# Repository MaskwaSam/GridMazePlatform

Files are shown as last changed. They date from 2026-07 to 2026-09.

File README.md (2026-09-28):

# Grid Maze Platform

Parametric Rhino 8 generator for a first-pass modular grid maze platform.

The shared platform system uses:

- 200 mm x 200 mm tile footprint.
- 10 mm total tile height.
- Selectable underside connector pockets for `north`, `south`, `east`, and `west`.
- 8 mm pocket depth from the underside, leaving a 2 mm top skin.
- A removable underside bridge connector that lays flat in a matching recess.
- Flat double-dovetail connector footprint:
  50 mm dovetail length into each board, 22 mm neck width, 46 mm inner tail width,
  6 mm connector thickness, and 0.2 mm printable clearance per side.
- No quarter-turn prongs, ramps, undercuts, or overhanging lock features.

The baseline platform generator intentionally leaves walls out. The working Rhino
model contains the user-authored straight maze-piece geometry with its platform and
tall walls; the wall-variant generators use that modeled geometry as their source
instead of rebuilding its profile from guessed dimensions.

## Files

- `params/maze_platform_v1.json` contains the default dimensions.
- `enabled_sides` controls which dovetail pockets are generated. Default: all four sides.
- `scripts/generate_grid_maze_platform.py` validates parameters and generates Rhino geometry.
- `scripts/generate_maze_piece_variants.py` derives the five-piece 200 mm starter set from the working Rhino geometry.
- `scripts/generate_h2d_compatible_platforms.py` creates 200 x 300 mm and 300 x 300 mm H2D adapter platforms with the exact reviewed X1C pocket geometry.
- `scripts/generate_h2d_maze_variants.py` adds the Rhino-authored walls to five maze layouts at each H2D platform size and two 45-degree special pieces.
- `scripts/generate_30deg_ramp.py` creates the X1C-compatible straight-corridor ramp that rises 2 mm above the wall top.
- `scripts/generate_30deg_up_down_ramp.py` creates the symmetric 200 x 300 challenge ramp with a centred ridge.
- `scripts/generate_challenge_ramp_variants.py` creates the twelve-piece 200 x 300 H2D challenge collection.
- `scripts/optimize_for_3d_printing.py` ranks printable dovetail/clearance variants without requiring Rhino.
- `scripts/render_piece_catalog.py` renders the generated STL files for the offline visual catalog.
- `tests/test_platform_spec.py` performs fast CPython checks that do not require Rhino.
- `reference/photos/` contains photos of printed prototypes; these are visual references, not dimensional source files.
- [`docs/index.html`](docs/index.html) is the human-readable catalog with geometry renders and connection diagrams.
- [`game/`](game/) is the self-hosted Chromebook game for programming a Three.js sphere robot with Blocks or Python.
- `output/` is where generated `.3dm` and `.stl` files are written.

The Rhino model at `output/grid_maze_platform_10mm_v1.3dm` is the authoritative
geometry for new maze-piece variants. Prototype photos should be used to understand
the intended assembly and appearance, while dimensions should be taken from the
Rhino geometry and parameter files.

## Project Handoff — 2026-08-29

The current visual catalog contains 33 generated pieces across six families:

- 5 original 200 x 200 mm X1C wall pieces;
- 2 blank H2D adapter platforms;
- 12 H2D wall and 45-degree adapter pieces;
- 1 X1C 30-degree rising ramp;
- 1 H2D 200 x 300 mm up-and-down ramp; and
- 12 H2D 200 x 300 mm challenge-ramp variations.

Open [`docs/index.html`](docs/index.html) directly in a browser to review the
renders and download the printable files. Its controls combine free-text search
with mutually exclusive platform and piece-type filters. Select **H2D only** to
hide the original X1C/200-only pieces. Press Escape to clear the search field;
use **Reset filters** to restore the complete catalog. All content remains visible
if JavaScript is unavailable.

Every new H2D platform keeps the reviewed X1C connector geometry unchanged and
uses one connector pocket centred on each side. The generated files in `output/`
remain the printable/editable deliverables; the catalog images are previews only.

Closeout verification: `python3 -B -m unittest discover -s tests -p 'test_*.py'`
passes all 88 tests, including generated-solid checks, the standalone game
contract, and catalog metadata, local-link, accessibility-state, and no-JavaScript
fallback checks. The catalog's inline JavaScript also passed syntax and filter-logic
validation; Maskwa Maze Lab additionally passed live Chromium interaction testing at
the 1366 x 768 Chromebook viewport.

Before a production print, slice the 300 x 300 mm platform with the intended H2D
nozzle/profile and confirm the usable-bed boundary, excluded zones, skirt, and brim.
Print a small connector test first when changing filament, nozzle, or clearance;
the CAD compatibility does not replace a physical fit check.

## Maskwa Maze Lab — Standalone Chromebook Game

[`game/index.html`](game/index.html) is the playable vertical slice. It uses the
generated straight, corner, and end-piece STLs to provide seven progressively
longer courses: Straight Start, Starter L-Turn, Mirror Left, Double Turn, U-Turn
Trail, Return Route, and Four-Turn Finish. Students choose a maze, drag the sphere robot from its tray
anywhere onto the highlighted starting piece, finish an intentionally incomplete program in
Blockly or Python, and press Run. The deterministic 60 Hz simulation reports
collisions and succeeds only when the robot enters the goal. Run and Reset preserve
the student's exact collision-safe drop position rather than snapping to the tile center.
The rendered sphere and physics collider are both 70 mm in diameter (35 mm
radius), exactly 35% of one 200 mm X1C plate width.

Every Run keeps the exact executed code, result, ending pose, and wall-impact
count in a per-maze history; students can also create explicit Save checkpoints
and compare changed lines. The latest 20 entries per maze remain in browser-local
storage. Export writes all maze work and history to one portable Maskwa Maze Lab JSON file.
Import validates the complete file, preserves replaced local code in history, and
never runs imported student code automatically. It also restores the exported
active maze. Failed autosaves remain visibly flagged, block a lossy maze switch,
and Export can produce an in-memory recovery copy when browser storage is
unavailable. If the complete project exceeds the portable-file limit, Export
falls back to a clearly named current-maze-only recovery file.

The app is self-hosted: Three.js, Blockly, the Python generator, and the minimal
Pyodide runtime are stored under `game/vendor/`, with their license notices. It
does not require a CDN. Serve it over HTTP rather than opening it with `file://`:

```bash
python3 -m http.server 8766 --directory game
```

Then open `http://127.0.0.1:8766/` in Chrome or ChromeOS. Validate the standalone
bundle and its deterministic reference solution with:

```bash
node game/tests/validate.mjs
```

The MVP has seven flat continuous-corridor levels with a picker, per-level program
saves, and a Next maze action. Ramp physics, branching T/cross-piece levels, the
rendered 8 x 8 shell matrix, and physical BOLT+ connectivity remain later additions. See
[`game/README.md`](game/README.md) for the student workflow, architecture, safety
boundary, offline behavior, and current limitations.

### Production acceptance — 2026-08-30

Maskwa Maze Lab is live at <https://mazelab.spatterson.ca>. The accepted release
is commit `3b51f351a5083f8f7886f102165514c8ed166bf9`, immutable image
`mazelab:3b51f351a508-3adc281d9e56`, and runtime digest
`3adc281d9e564466a6f78de723d326c1807c5490816514c1626e8390e960a3f2`.
Public HTTP, the version 40 offline cache, all seven Beginning levels, Blocks,
local Python, the 390 x 844 mobile layout, and the no-external-request boundary
passed acceptance. The operator completed visual acceptance and reported being
very happy with the result.

The Cloudflare connector and running neighboring services were preserved during
the update. The prior image `mazelab:a484fc7c9452-463b9b81691d` remains retained
for rollback. Maze Lab remains a static, local-first application: student work
stays in each browser, and the dormant multiplayer modules do not expose a
WebSocket or `/ws` service. This production acceptance applies only to the
committed game and deployment surface; the separate CAD/catalogue work remains
outside the deployed artifact.

## Maze Piece Starter Set

The canonical set keeps the existing 200 mm square module and includes straight,
corner, T-junction, cross-junction, and end/dead-end pieces. Other orientations are
made by rotating these five pieces.

Generate the Rhino and STL files with Rhino 8's `rhinocode` command:

```bash
/Applications/Rhino\ 8.app/Contents/Resources/bin/rhinocode script \
  "$(pwd)/scripts/generate_maze_piece_variants.py"
```

Then validate the exported artifacts and refresh the catalog images:

```bash
python3 -B scripts/generate_maze_piece_variants.py --check --require-outputs
python3 -B scripts/render_piece_catalog.py
```

Generated variants are written to `output/variants/`.

The variant generator pins the reviewed source model's SHA-256 fingerprint so it
cannot silently select different geometry after the Rhino file changes. After an
intentional source edit, review the new geometry before updating
`EXPECTED_SOURCE_SHA256` in the generator.

## H2D-Compatible Adapter Platforms

The H2D set expands the printable area while retaining the current X1C maze
connector at its original size and clearance:

- `200 x 300 mm`: one connector bay centred on each of its four edges.
- `300 x 300 mm`: one connector bay centred on each of its four edges.
- Both platforms remain 10 mm high, with 8 mm-deep underside pockets and a
  2 mm top skin.

On a 300 mm edge, an ordinary 200 x 200 mm X1C platform attaches in the centre,
leaving a 50 mm shoulder at each end of the larger edge. The connector itself is
not scaled or altered.

Generate the H2D adapters through Rhino 8, then validate their saved geometry:

```bash
/Applications/Rhino\ 8.app/Contents/Resources/bin/rhinocode script \
  "$(pwd)/scripts/generate_h2d_compatible_platforms.py"
python3 -B scripts/generate_h2d_compatible_platforms.py --check --require-outputs
python3 -B scripts/render_piece_catalog.py --collection h2d
```

Generated files are written to `output/h2d-platforms/`. For H2D dual-nozzle
printing, orient the 200 x 300 mm adapter with its 300 mm dimension along the
320 mm bed axis. The 300 x 300 mm adapter uses the dual-nozzle width exactly, so
the single-nozzle build envelope is the more forgiving choice. Confirm the
sliced footprint, skirt or brim, and excluded zones before printing either part.

## H2D Wall Variants

The larger wall set contains straight, corner, T-junction, cross-junction, and
end/dead-end pieces at both 200 x 300 mm and 300 x 300 mm. Every piece retains one
centred X1C connector pocket per side. A wall-bearing transition connects a centred
200 mm X1C edge to a centred 300 mm H2D edge. A four-way 300 x 300 mm hub provides
centred 200 mm X1C openings and connectors on all four sides.

The walls come from the separate closed wall solids in the working Rhino file.
For a 300 mm edge, the generator preserves both designed wall ends and inserts
100 mm through a verified uniform middle section. It does not scale the wall
thickness, height, or end transitions.

The transition occupies a 300 x 200 mm envelope. Its side walls run straight for
75 mm, widen by 50 mm over a 50 mm run at exactly 45 degrees, and then run straight
for another 75 mm. It has one centred connector pocket on each open end and no
connector pockets on its angled sides. A continuous sharp-miter sweep carries the
verified Rhino wall profile through both bends without overlap ribs.

The four-way hub uses four exact 45-degree walls. Each wall is the source-derived
1.2 mm vertical panel from Z10 to Z82; the authored 19.2 mm sloped reinforcement
foot is intentionally omitted from this piece. This removes the triangular foot
corners while retaining the wall height, four centred openings, and connector scale.

Generate, validate, and render the twelve-piece set with:

```bash
/Applications/Rhino\ 8.app/Contents/Resources/bin/rhinocode script \
  "$(pwd)/scripts/generate_h2d_maze_variants.py"
python3 -B scripts/generate_h2d_maze_variants.py --check --require-outputs
python3 -B scripts/render_piece_catalog.py --collection h2d-walls
```

The STL files and combined editable Rhino model are written to
`output/h2d-wall-variants/`.

## 30 Degree Ramp

The ramp is a 200 x 200 mm X1C-compatible straight-corridor tile with one centred
connector pocket on every side and the two authored side walls. Its floor remains
flat at Z10 for a 71.828 mm south approach, then rises at exactly 30 degrees to
Z84 at the north edge. That is 2 mm above the Z82 wall top. The 74 mm rise fixes
the horizontal run at 128.172 mm and the sloped surface length at exactly 148 mm.

The closed ramp wedge is 161.6 mm wide, centred between X19.2 and X180.8 so it
stays within the exact floor-level corridor between the authored wall feet. Rotate
the finished tile to place the high edge in another direction. The high-side pocket
remains mechanically compatible, but its Z84 ramp surface is intentionally not a
level continuation of a normal Z10 tile.

Generate, validate, and render the ramp with:

```bash
/Applications/Rhino\ 8.app/Contents/Resources/bin/rhinocode script \
  "$(pwd)/scripts/generate_30deg_ramp.py"
python3 -B scripts/generate_30deg_ramp.py --check --require-outputs
python3 -B scripts/render_piece_catalog.py --collection ramp
```

The printable STL and editable one-piece Rhino model are written to `output/ramp/`.

### 200 x 300 Up-and-Down Challenge Ramp

The challenge piece keeps both entries at the normal Z10 floor level. After a
21.828 mm flat approach, it climbs at exactly 30 degrees to a centred Z84 ridge,
then descends symmetrically at 30 degrees to a matching 21.828 mm exit approach.
Each side of the ridge has a 74 mm rise, 128.172 mm horizontal run, and 148 mm
sloped length. The peak is 2 mm above the Z82 wall top.

Its 200 x 300 mm H2D platform retains one centred X1C pocket on every side and
uses the reviewed 300 mm extensions of the two authored straight walls. The ramp
remains 161.6 mm wide between the wall feet. Generate and verify it with:

```bash
/Applications/Rhino\ 8.app/Contents/Resources/bin/rhinocode script \
  "$(pwd)/scripts/generate_30deg_up_down_ramp.py"
python3 -B scripts/generate_30deg_up_down_ramp.py --check --require-outputs
python3 -B scripts/render_piece_catalog.py --collection challenge-ramp
```

Its STL and editable Rhino model are written to `output/challenge-ramp/`.

### 200 x 300 Challenge Ramp Collection

The extended challenge collection reuses the same H2D platform, exact centred
X1C connector pocket on every side, 161.6 mm ramp width, and source-derived wall
geometry. It contains twelve printable profiles:

- a Z84 hill with a 30 mm flat top;
- two 30 mm-rise humps;
- the Z84 ridge with twelve shallow traction ribs;
- centred 20, 40, and 60 mm-rise hills;
- an asymmetric ridge offset to Y100;
- a Z84 crest rounded to a 15 mm radius;
- a Z60 stopping platform that is 80 mm long;
- one-wall and wall-free versions of the Z84 ridge; and
- a directional challenge with a smooth 30-degree climb and ten steps down.

Generate, validate, and render the collection with:

```bash
/Applications/Rhino\ 8.app/Contents/Resources/bin/rhinocode script \
  "$(pwd)/scripts/generate_challenge_ramp_variants.py"
python3 -B scripts/generate_challenge_ramp_variants.py --check --require-outputs
python3 -B scripts/render_piece_catalog.py --collection challenge-ramp-variants
```

The twelve STLs and their combined editable Rhino model are written to
`output/challenge-ramp-variants/`.

## Generate

From Rhino 8, with model units in millimeters:

```text
-_RunPythonScript "<repo-path>/scripts/generate_grid_maze_platform.py"
```

Replace `<repo-path>` with the folder where you cloned this repository.

The script also supports Rhino headless execution and writes status files to:

```text
output/grid_maze_platform_status.txt
<Rhino system temp>/grid_maze_platform_status.txt
```

Expected output files:

- `output/grid_maze_platform_10mm_v1.3dm`
- `output/grid_maze_platform_tile_v1.stl`
- `output/grid_maze_platform_bridge_v1.stl`
- `output/grid_maze_platform_recess_cutter_v1.stl` contains the full board-layout dovetail cutter for all four underside connector beds.

Rhino may include a local macOS render-cache username in otherwise portable
`.3dm` metadata. The checked-in model is sanitized with the length-preserving
`scripts/sanitize_3dm_metadata.py` helper; generated geometry is unchanged.

## Fast Checks

These checks only validate the parameter math and can run outside Rhino:

```bash
python3 -B -m unittest discover -s tests
python3 -B scripts/generate_grid_maze_platform.py --check
python3 -B scripts/generate_grid_maze_platform.py --check --sides north,east
python3 -B scripts/optimize_for_3d_printing.py
```

To generate only selected sides from Rhino, edit `enabled_sides` in
`params/maze_platform_v1.json` before running the Rhino script. From CPython checks
and non-Rhino runs, `--sides north,east` can be used as a quick override.

## 3D Print Optimization

The optimizer reads the current platform parameters and scores small dovetail
variants for FDM printing. It does not change the main parameter file unless you
ask it to write a separate optimized JSON.

```bash
python3 -B scripts/optimize_for_3d_printing.py --profile tight
python3 -B scripts/optimize_for_3d_printing.py --profile balanced --write-report
python3 -B scripts/optimize_for_3d_printing.py --profile balanced --write-params
```

Profiles:

- `tight` keeps the requested 0.20 mm clearance as the target.
- `balanced` targets 0.25 mm clearance for a more forgiving first FDM prototype.
- `durable` favors a slightly thicker connector and lower vertical slack.

Generated optional files:

- `output/print_optimization_report.md`
- `params/maze_platform_print_optimized.json`

## Current Assumptions

- This is tabletop-maze hardware, not a child/adult load-bearing floor system.
- The underside bridge is a flat printed dovetail part that sits inside the 8 mm underside recess.
- The platform-side pocket is a simple subtractive dovetail bed for the connector footprint.
- The exported recess cutter includes the board layout, not just the loose connector footprint.
- The current flat connector is shape-fit only; screw/nut retention can be added next.

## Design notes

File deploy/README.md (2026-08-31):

# Maskwa Maze Lab production deployment

This package serves the committed standalone game at
`https://mazelab.spatterson.ca` from a dedicated, non-root NGINX container.
The application has no backend, server-side student data, host port, remote
runtime dependency, or persistent volume. Student code, placements, and attempt
history stay in the browser; `.maskwamaze` export/import is the portable recovery
path.

The game includes dormant versioned multiplayer client modules, but this release
still has no WebSocket service and no `/ws` route. Loading the app does not open a
socket. Do not point the client at an ad hoc WebSocket server. The authority,
privacy, ordering, security, two-Chromebook, and rollback gates for a future
same-origin `wss://mazelab.spatterson.ca/ws` service are specified in
`game/MULTIPLAYER.md`.

## Request path and service URL

```text
Browser -> Cloudflare edge -> managed spatterson-site Tunnel
        -> standalone spatterson-cloudflared -> mazelab_edge
        -> mazelab:8080 -> NGINX
```

Use these Cloudflare **Published application** fields only after private origin
verification succeeds:

- Subdomain: `mazelab`
- Domain: `spatterson.ca`
- Path: leave blank
- Service URL: `http://mazelab:8080`

The Compose project joins only the pre-created internal `mazelab_edge` network.
Attach the existing connector to that network without disconnecting it from any
existing network and without restarting or recreating the connector. Do not
publish a host port, change router forwarding, modify the main-site `web`
service, or touch PatterDraw, GeoGon, Moodle, or `mesconline.ca`.

## Release gate

1. Commit the exact `game/`, `deploy/`, level-generator, and two release-test
   files.
2. Run `deploy/prepare-release.sh /absolute/new/release-directory`. The script
   refuses an uncommitted release surface, derives the full commit and runtime
   digest, archives that exact commit, reruns the game/deployment tests from the
   extracted archive, and writes `release.env` plus a human-readable receipt.
   Unrelated CAD/catalog work may remain in the checkout because it is not copied
   into or used to label this release.
3. Independently verify the source-archive SHA-256 from the receipt after every
   transfer and before extraction. Load only the generated `release.env`; do not
   hand-type release identity values.
4. Render the Compose model and confirm that it contains no `ports` entry and
   names only `mazelab_edge`.

The image build checks the 40-character Git commit and both 64-character receipt
digests, recomputes the exact allowlisted runtime digest, rejects symlinks, copies
only the declared runtime surface, validates NGINX, and records the release
identity in OCI labels. The source-archive digest is independently rechecked
before remote extraction; the container never trusts a dirty working directory.

## Initial deployment gates

Before any mutation, record:

- the current public DNS/Tunnel route state for `mazelab.spatterson.ca`;
- the absence or exact state of a `mazelab` container, image, target directory,
  and `mazelab_edge` network;
- the connector container ID, image, restart count, and complete network list;
- neighboring service health and host listeners.

Create only an internal `mazelab_edge` network. Build and start only the
`mazelab` service while the connector is still absent from that network. Run
`deploy/verify-running.sh private` and prove the correct Host returns the health
endpoint and app, an unknown Host is rejected, the WebAssembly response uses
`application/wasm`, the service worker and HTML are `no-store`, missing files
are 404, and the container is non-root, read-only, capability-free,
resource-bounded, log-bounded, and has no published host port.

For a private origin temporarily exposed to the operator workstation, run
`python3 deploy/verify-browser.py --base-url <private-origin>`. It proves that
Three.js, Blockly, and the local Pyodide worker initialize under the production
headers and that the page makes no cross-origin application requests. Remove
the temporary operator-only port or proxy immediately after this check; the
production Compose model must remain host-port-free.

After private acceptance, attach the existing connector to `mazelab_edge`
without restarting it. Run `deploy/verify-running.sh connector-attached`, then
add the Cloudflare route above. The attached verifier requires the pre-attachment
connector ID, image ID, restart count, and sorted network list in the documented
`MAZELAB_CONNECTOR_*_BEFORE` variables; it rejects identity, restart, or neighboring
network drift and probes `mazelab:8080` from a disposable process sharing the
connector's network namespace. Public acceptance must cover HTTPS, the expected
headers, a fresh-profile PWA load, all seven mazes, Blockly and Python execution,
the local Pyodide worker, a `.maskwamaze` export/import round trip, offline reload,
fullscreen, and absence of external application requests. Recheck
`spatterson.ca`, `bible.spatterson.ca`, `draw.spatterson.ca`,
`geogon.spatterson.ca`, and `mesconline.ca` after attachment and after route
activation.

## Rollback

Retain the exact pre-deploy connector and public route state, release archive,
image ID, labels, rendered Compose model, and verification output through the
rollback window. Initial rollback is narrowly scoped:

1. Remove only the `mazelab.spatterson.ca` Published application route and
   verify or remove only its managed DNS record.
2. Disconnect only `spatterson-cloudflared` from `mazelab_edge`; do not restart
   or recreate the connector.
3. Stop only the `mazelab` Compose project.
4. Remove `mazelab_edge` only after proving that no container remains attached.

Do not delete the staged release or accepted image until the rollback window has
closed.

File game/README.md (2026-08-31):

# Maskwa Maze Lab — standalone Chromebook MVP

Maskwa Maze Lab is a static, self-hosted Three.js game with seven progressively
longer printable-piece mazes. A student chooses a level, places the sphere robot
anywhere collision-safe on the highlighted starting piece, writes a program with
Blockly or Python, presses Run,
and watches the robot attempt the same deterministic maze every time. The
robot accelerates, rolls with momentum, actively brakes, and rebounds from maze
walls while continuing the student's command. Its white band and orange tracker
rotate with the physical shell so students can see its speed and rolling direction;
the upright arrow remains the separate facing indicator.

The game uses the printable models' millimetre scale. The sphere is 70 mm in
diameter (35 mm radius), exactly 35% of a 200 mm X1C plate width. Its rendered
mesh and physics collider use the same radius.

## Run it

From the repository root:

```bash
python3 -m http.server 8766 --directory game
```

Then open `http://127.0.0.1:8766/` in current Chrome or ChromeOS. Do not open
`index.html` with `file://`; browser modules, workers, WebAssembly, and offline
caching require HTTP(S). A production static host must serve `.wasm` as
`application/wasm`.

On a phone, portrait mode presents the maze and Coding Workspace as a compact
top-to-bottom workflow with a sticky level header and 44 px primary touch
targets. Narrow screens stack the maze title above its controls so labels stay
readable. Short landscape screens use a balanced side-by-side view and remove
nonessential maze overlays so placing the robot remains practical. Safe-area
insets are respected around notches and home indicators; rotate the device at
any time and the Three.js and Blockly surfaces resize without discarding student
work.

The first Python run loads about 11.7 MiB of local Pyodide files. After the
service worker finishes caching, the game can reload offline from the same
origin. There are no CDN or external runtime requests.

## Student workflow

1. Choose any of the seven unlocked mazes. The sequence progresses from a
   Straight Start, Starter L-Turn, Mirror Left, Double Turn, U-Turn Trail,
   Return Route, and Four-Turn Finish challenges.
2. Drag the robot from its tray anywhere onto the highlighted blue START piece.
   The exact release point becomes that attempt's starting position. **Place at
   start center** remains an explicit shortcut. Every classroom level starts
   facing north at world bearing `0°`. The `N` on the START AREA label means
   North and marks the robot’s initial forward direction. After the robot turns,
   its new facing becomes the reference for subsequent forward commands.
3. Complete the deliberately unfinished starter blocks, or switch to Python.
4. Press **Run**. **Stop** terminates the Python worker. **Reset** restores the
   exact position the student chose and clears the trail.
   When the maze and robot have been idle for 20 seconds, the camera begins a
   slow orbit for a clearer view. Any pointer, wheel, or keyboard interaction
   stops the orbit; reduced-motion preferences disable it.
   Click the maze to focus it, then press **Ctrl+R** to start that orbit
   immediately. The browser's normal reload shortcut remains available whenever
   focus is outside the maze view.
   Use the expand button in either panel header to focus the maze or Coding Workspace
   fullscreen. Press the same button or `Esc` to return to the two-panel view.
5. Bring the sphere to a complete stop on the green GOAL disc. Crossing the
   disc while still moving does not solve the maze. Wall impacts are counted in
   telemetry, but they bounce the robot back into the maze and do not terminate
   the program.
6. Select **Next maze** after a successful run, or use the maze picker at any
   time. Blocks and independent Python are saved separately for each level.
7. Use **Attempts** to compare the exact code, result, wall impacts, and changed
   line count from oldest to newest. Every Run is recorded automatically; **Save**
   adds a deliberate code-version checkpoint. The latest 20 entries are kept for
   each maze.

Use **Export** to download one `Maskwa-Maze-Lab-Work-YYYY-MM-DD.maskwamaze.json` file
containing every saved maze, its exact editor state, robot placement, and attempt
history. **Import** accepts that file on another Chromebook and continues to
accept earlier `.mazebot.json` project files. It validates the
entire project before changing local storage, replaces only the mazes included in
the file, and keeps the current local code for each replaced maze as a **Before
import** history entry. Imported code is displayed but never run automatically.
Mazes omitted from the file keep their local work, and the maze that was active
when the project was exported opens after import.

Python editing is limited to the same 20,000 characters accepted by the local
runtime. If an autosave fails because browser storage is blocked or full, the UI
keeps a visible warning, prevents a maze change that would hide the unsaved work,
and **Export** still attempts to download an in-memory recovery copy containing
the current maze. If the complete project has grown beyond the 3 MB portable-file
limit, Export downloads a clearly named current-maze-only recovery file instead.

Blocks generate Python one way. As soon as a student edits the Python buffer it
becomes independent; edits never alter or discard the saved blocks. The UI
labels this state and asks before replacing edited Python with freshly generated
block code. Blockly state, Python state, active editor, current level, and the
exact chosen starting position are saved to browser local storage. The v3 save
format keeps one program record plus a bounded attempt history per maze, and
imports the prior robot-relative v2 record without deleting it. The portable
project file identifies its schema and robot-relative heading rules so an
incompatible file is rejected before any work changes. Older absolute-heading v1
data remains as an untouched backup and is not silently executed under the newer
relative-heading rules.

Python accepts both `await set_main_led("#008cff")` and the RGB-number
`await set_main_led(0, 140, 255)` form.

Motion angles are robot-relative. `roll(0, ...)` always means forward from the
sphere's current facing; `roll(90, ...)` turns right before rolling, and
`roll(-90, ...)` turns left. `spin(90, ...)` turns right in place and makes that
new facing the reference for the next command, so a following `roll(0, ...)`
continues in the direction established by the spin. Telemetry reports the
resulting world bearing from the original north-facing start.

## Device settings

The header **Settings** menu stores presentation and convenience choices only on
the current browser device. It includes idle camera tour, reduced motion, a
fog-free clearer view, travel trail, impact markers, ground grid, and optional
reset confirmation. It also has an opt-in **Xbox controller** switch. Pair the
controller in ChromeOS Bluetooth first, return to the game, enable the switch,
and press any controller button. The status card identifies whether the browser
is waiting, connected, disconnected, or unsupported and shows the complete
button map. Controller support starts off and performs no polling while disabled.

The Xbox mapping is A for Place/Run, B for Stop, X for Reset, Y for
Blocks/Python, View for Attempts, Menu for Settings, and the bumpers or left/right
D-pad buttons for maze navigation. These buttons operate the game workflow only;
they never steer the sphere. Robot motion and turning still come exclusively
from the student's Blocks or Python program, with the same timing and physics.

Defaults keep the tour, trail, impact markers, and grid on;
the other options start off. Reduced motion changes camera and sphere
animation only, never timing, collision, bounce, heading, or goal physics.

Settings use their own versioned local-storage record. They are not included in
student autosaves, attempt history, Export files, or Import, so moving class work
between Chromebooks cannot silently change a device's accessibility preferences.
**Restore defaults** changes only these settings and leaves every program and
attempt untouched.

## Architecture and safety boundary

- `levels/*.json` describes each X1C route using the three existing STL models,
  including physical end-caps behind START and GOAL. Every file records visual
  transforms, start/goal poses, physics constants, a logical wall polygon, and a
  deterministic reference program.
- `js/levels.js` is the ordered classroom catalogue used by the picker and the
  Next maze action. `scripts/generate_game_levels.mjs` converts short 200 mm grid
  paths into correctly rotated printable pieces, collision outlines, and reference
  programs. Run it with `--write` after adding a path, or without an option to
  check that generated JSON is current.
- `js/simulation.js` displays the source STL meshes. Collision uses both the
  level boundary and wall segments generated from every printable tile's closed
  sides. A final containment check refuses to render any illegal position. This
  stays responsive on Chromebooks without relying on expensive triangle meshes.
- `js/level-logic.js` is the deterministic 60 Hz rolling-physics contract shared
  by the browser and validation script. Speed 160 targets 100 mm/s, acceleration
  and braking change velocity over time, and wall normals produce damped rebounds.
- `js/blocks.js` defines 13 custom blocks for sphere-robot commands: motion,
  LEDs, matrix pixels, and sensor reads, with Python generators.
- `js/python-worker.js` runs student Python inside a dedicated worker. It rejects
  imports, attribute access, classes, globals, and reserved names; only safe
  built-ins and the allowlisted robot RPC functions enter the student namespace.
- `js/python-runtime.js` enforces a 20,000-character program limit, a 25-second
  run limit, and hard termination for Stop. Termination/recreation avoids a
  SharedArrayBuffer or cross-origin-isolation requirement on Chromebooks.
- `js/storage.js` owns per-level autosave, the latest-20 code history, and the
  versioned portable JSON contract. Imports are size-limited, schema-checked,
  Blockly-validated, staged in memory, and committed with one local-storage
  write only after student confirmation.
- `js/game-actions.js` is the shared workflow boundary for on-screen and Xbox
  controller input. `js/gamepad.js` adapts the browser Gamepad API into rising-edge
  semantic actions without held-button repeats or direct robot steering.
- The multiplayer protocol, immutable session, transport, and client modules are
  dormant groundwork for a later authoritative WebSocket service. The current
  release remains offline by default and opens no socket. See
  [MULTIPLAYER.md](MULTIPLAYER.md) for the privacy, ordering, authority, and
  deployment contract.

This is an instructional sandbox, not a security boundary for hostile code.
The AST restrictions, isolated worker, program limit, and hard timeout reduce
accidental misuse; a school deployment should still use an origin containing no
sensitive data or authenticated application APIs.

## Validate

From the repository root:

```bash
node game/tests/validate.mjs
```

The validation checks local-only dependencies, JavaScript syntax, required UI
controls, the exact 13 custom blocks, worker restrictions, STL integrity, wall
bounce behavior, command semantics, catalogue/cache completeness, per-level save
isolation, attempt lifecycle, loss-resistant import/export behavior, and every
level's deterministic reference solution. A maze level is
not accepted unless its start and goal are legal, every printable opening connects
correctly, its polygon matches the printed corridor, and its saved student-command
route reaches the goal without an impact.
The three canonical X1C meshes are checksum-pinned, and the validator reads the
top-wall orientation directly from each STL. A rotated or changed printable wall
therefore cannot silently drift away from the logical collision profile.

## Current MVP limits

- The seven included routes are continuous corridors made from end, straight,
  and corner pieces. True branching mazes require adding the printable T and
  four-way pieces to the game geometry and collision profiles.
- There is no visual level builder yet; new continuous routes are currently
  defined as grid paths in the generator script.
- Physics is currently a deterministic 2-D rolling model. Ramps, falling, and
  vertical gravity are not simulated yet.
- Matrix commands preserve an 8×8 virtual state but do not yet render a matrix
  on the sphere shell.
- Python deliberately excludes imports and attribute access, so lessons use the
  provided robot functions and safe core language constructs.
- No physical-robot connection, accounts, live multiplayer server, or
  leaderboard. Multiplayer-ready client boundaries are present but remain
  offline until a separately reviewed server is explicitly configured.

See `THIRD_PARTY_NOTICES.md` for local runtime licenses.

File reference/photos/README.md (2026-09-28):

# Prototype Photos

- `IMG_6221-preview.jpg` shows the existing red platform panels and white
  maze-wall pieces assembled as straight runs and a junction. The shared JPEG
  has no EXIF metadata.
- The untouched camera original, `IMG_6221.HEIC`, is retained locally and is
  excluded from the public repository.

These photos document the intended physical system. They are not scale references.
Use `output/grid_maze_platform_10mm_v1.3dm` and the files in `params/` for dimensions
when creating additional pieces.

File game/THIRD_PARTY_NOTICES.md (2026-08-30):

# Third-party notices

Maskwa Maze Lab is self-hosted and makes no CDN requests. The following local
runtime files are redistributed unchanged:

- Three.js 0.181.2 core/module builds and its STLLoader/OrbitControls examples — MIT License.
  See `vendor/licenses/Three-MIT.txt`.
- Blockly 13.1.1 and its Python generator — Apache License 2.0.
  See `vendor/licenses/Blockly-Apache-2.0.txt`.
- Pyodide 0.29.0 core runtime — Mozilla Public License 2.0.
  See `vendor/licenses/Pyodide-MPL-2.0.txt`.

The three STL files in `assets/stl/` are copies of the project's own tested
X1C maze-piece outputs. They remain governed by the project-level license.

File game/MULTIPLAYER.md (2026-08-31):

# Maskwa Maze Lab multiplayer contract

## Current release status

Maskwa Maze Lab is still an offline-first, single-student game. The production
container is static NGINX and does **not** expose `/ws`, create rooms, or send
student data to a server. The multiplayer modules in this release are a dormant,
tested client boundary for a later server implementation; they do not activate a
network connection by themselves.

This distinction is intentional. A classroom release must not quietly begin
transmitting student activity just because multiplayer-ready code is present.

## Client boundaries

- `js/game-actions.js` normalizes touch, mouse, keyboard, and controller workflow
  actions before the game handles them. Only placement, Run, Stop, Reset,
  Run-again, and maze-navigation actions are shareable. Settings, attempt-history
  views, and editor-mode changes remain device-local.
- `js/multiplayer-protocol.js` owns the version-1 wire envelope, strict message
  and payload validation, message-size limit, robot-command allowlist, and secure
  endpoint validation.
- `js/multiplayer-session.js` is the immutable room projection. It applies
  ordered server events, rejects duplicates, detects sequence gaps, and replaces
  state only from a validated room snapshot.
- `js/multiplayer-transport.js` provides an offline default, a deterministic
  loopback transport for two-client tests, and an explicitly activated WebSocket
  transport. The WebSocket class is not constructed and cannot reconnect until
  application code supplies a validated endpoint and calls `connect()`.
- `js/multiplayer-client.js` is the command-authority seam used by the Python
  runtime. Local simulation remains authoritative offline. A future room can
  opt into server command authority after the server confirms that authority.

The offline transport is the only production default. Reconnect never replays
robot commands because repeating a motion command after an uncertain disconnect
could produce a different maze result.

## Privacy contract

The future wire protocol may carry only normalized workflow intents, participant
display metadata, the selected level ID, bounded allowlisted robot commands,
and robot telemetry/state. It must never carry:

- Blockly workspace data or Python source;
- attempt-history code, notes, or outcomes;
- imported or exported project files;
- device settings, accessibility choices, or controller identity strings;
- browser-storage contents, filenames, or unrelated page data.

Those records remain local unless a later product decision introduces a clearly
labelled, separately consented classroom-storage feature.

## Version-1 message flow

Every envelope contains the fixed protocol name and version, a unique message ID,
participant ID, monotonic sequence, timestamp, optional room ID, and one strictly
validated payload. The maximum encoded message is 64 KiB. Server sequences are
scoped by a required opaque `serverEpoch`. A server must keep the epoch stable
while it can continue its sequence and must issue a new unpredictable epoch when
that sequence state resets, including after a non-persistent server restart.

1. The client opens a secure WebSocket and sends `hello`, including the paired
   `lastServerEpoch` and latest applied server sequence when reconnecting.
2. The first server frame must be `welcome`, which identifies the current
   `serverEpoch`. In the same epoch its sequence must continue exactly. A new
   epoch must start at sequence 1; the client first discards stale room state,
   deduplication IDs, synchronization state, and server authority. It then sends
   `room.join` for an explicitly chosen or reconnect-intended room and level.
3. The server returns a full `room.snapshot`. That snapshot establishes room
   membership, level, command authority, robots, tick, and server sequence.
4. Locally accepted shareable workflow input is sent as `action.intent`.
   Cancelled confirmations, failed preflight, and blocked controls emit nothing.
   Only the server can emit the ordered `action.commit` that other clients apply.
5. With server command authority, an allowlisted `robot.command` uses a unique
   request ID and resolves only from the matching `robot.result`. Robot state is
   published by the server as ordered `robot.state` messages.
6. Duplicate server sequences are ignored. A sequence gap causes `sync.request`;
   clients reject in-flight commands and wait for a fresh snapshot rather than
   guessing, sending more room input, or replaying commands.
7. `room.leave`, every socket close (including one being reconnected), an
   explicit endpoint replacement, and a server-to-local authority change return
   the client to local authority. Pending remote commands fail closed and are not
   replayed; late results from an old room membership are discarded. An explicit
   endpoint replacement also clears the prior room and server epoch before any
   new socket is constructed.

The server is authoritative for room membership, ordering, committed actions,
robot command execution, collision state, and goal state. Clients are renderers
and intent producers, not arbiters of another student's result.

## Future server and deployment requirements

The intended public endpoint is same-origin
`wss://mazelab.spatterson.ca/ws`. The client rejects every cross-origin endpoint
unless its exact WebSocket origin is supplied in an explicit allowlist. Local
development may use `ws://localhost` only from the matching localhost origin (or
an explicit development allowlist). It also rejects insecure non-localhost
WebSocket URLs and URLs containing embedded credentials or fragments.

The future server should be a separate least-privilege container on an internal
Compose network. NGINX can then proxy only `/ws` to that service with HTTP/1.1
upgrade headers and conservative timeouts. Keep the static app container
host-port-free. Do not overload the Cloudflare Tunnel route with a second public
hostname unless there is an explicit operational reason.

Before enabling `/ws`, the server and proxy release must prove all of the
following:

- HTTPS/WSS only in production, exact `Origin` allowlisting, no URL credentials,
  and short-lived unguessable room admission tokens;
- server-enforced student/teacher/observer roles and room membership on every
  message, with no trust in client-supplied authority;
- the same strict schema, command allowlist, 64 KiB message cap, participant cap,
  per-client and per-room rate limits, heartbeat timeout, and bounded queues;
- monotonic server sequences within a stable server epoch, a newly generated
  epoch whenever sequence state resets, idempotent message/request IDs,
  reconnect snapshot recovery, and no motion-command replay;
- no arbitrary Python execution on the server and no student code in application
  logs, metrics, traces, or crash reports;
- container health checks, resource limits, log limits, graceful drain, backup or
  explicit ephemeral-room policy, and a rollback that removes only `/ws` and its
  new service;
- two real Chromebook clients completing a room join, disconnect/reconnect,
  sequence-gap recovery, simultaneous action ordering, wall collision, and
  stopped-on-goal run without affecting offline play.

Until those gates pass, the public application remains single-student and the
offline transport remains the only enabled transport.

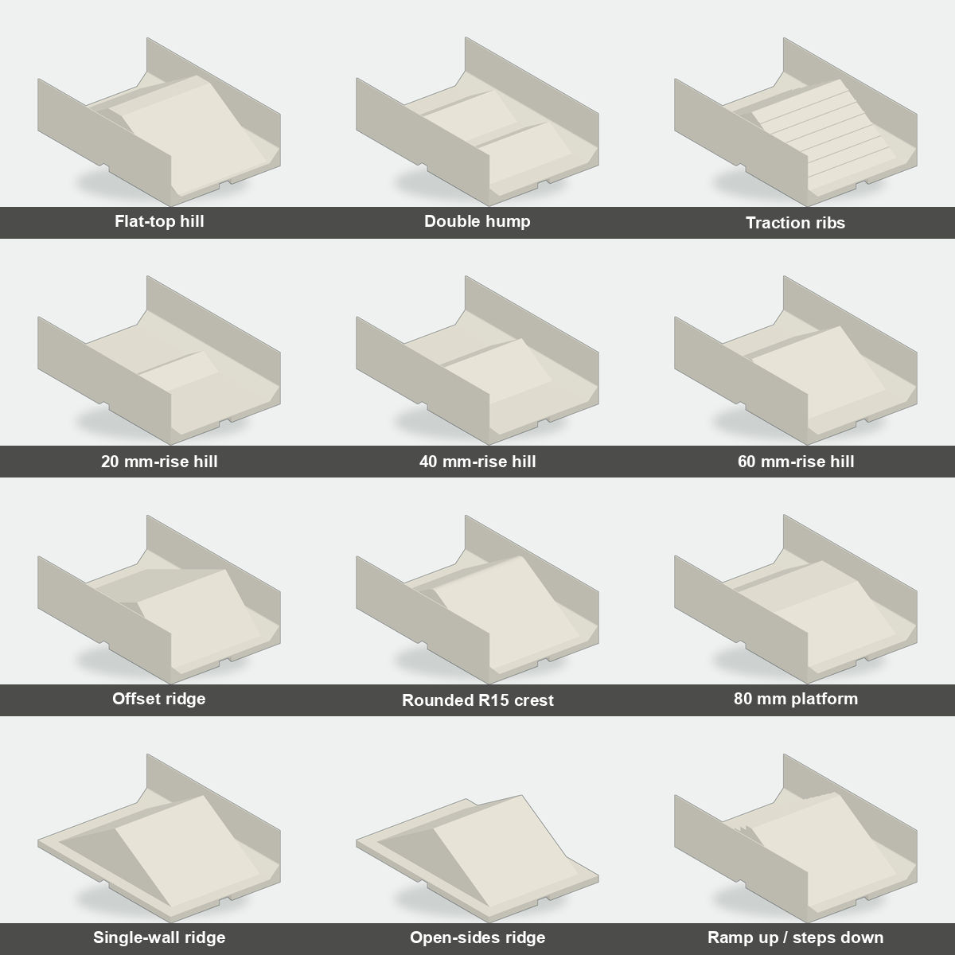
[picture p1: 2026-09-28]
docs/images/challenge-ramp-variants-overview.png

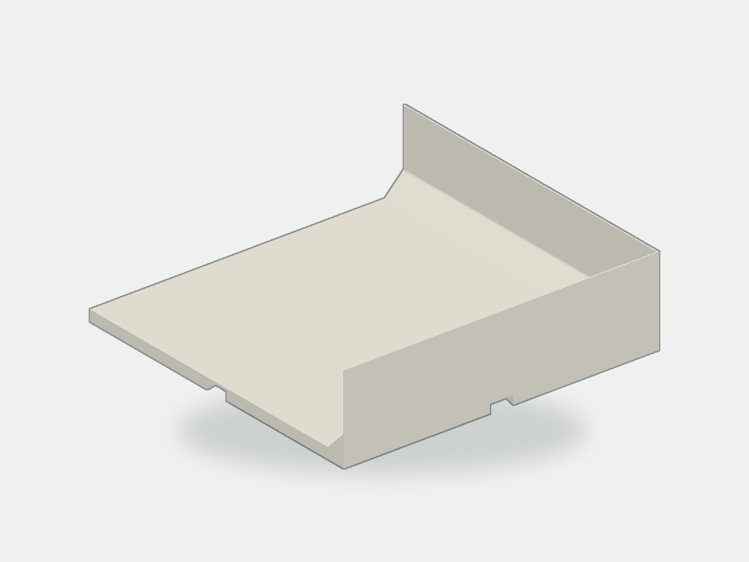
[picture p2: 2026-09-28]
docs/images/h2d-wall-300x300-corner.png

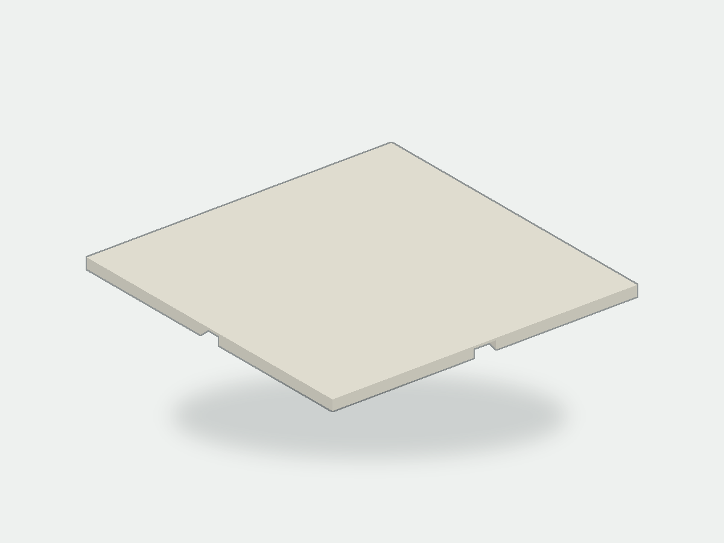
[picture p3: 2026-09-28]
docs/images/h2d-platform-300x300.png

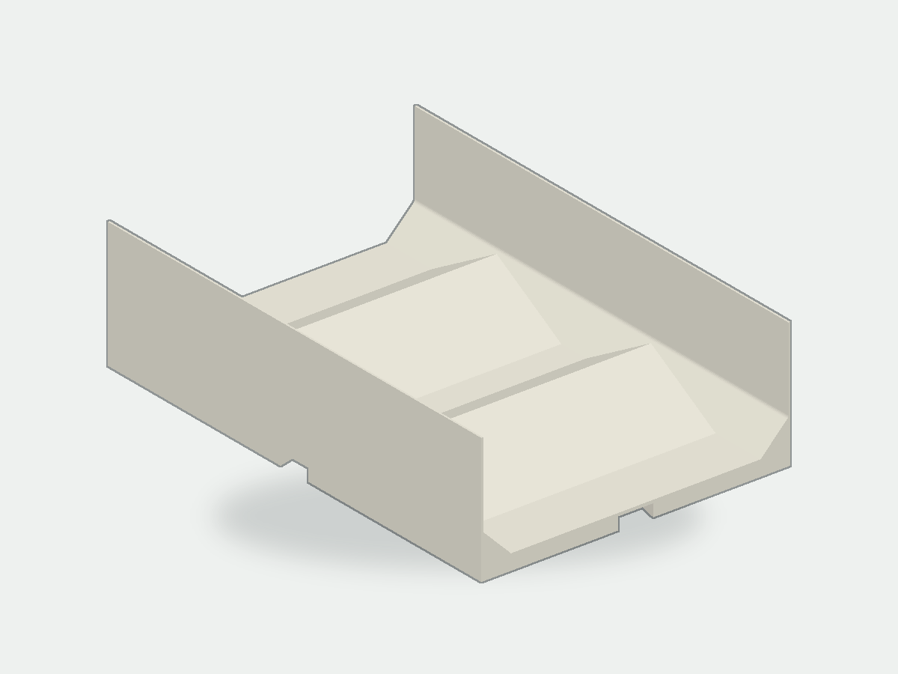
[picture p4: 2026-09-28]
docs/images/maze-piece-h2d-200x300-double-hump-30mm-rise.png

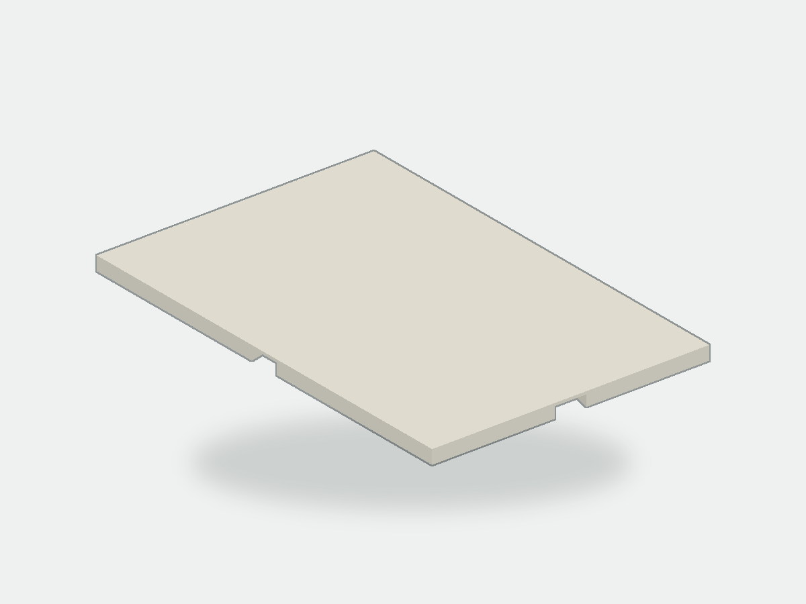
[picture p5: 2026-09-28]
docs/images/h2d-wall-200x300-cross-junction.png

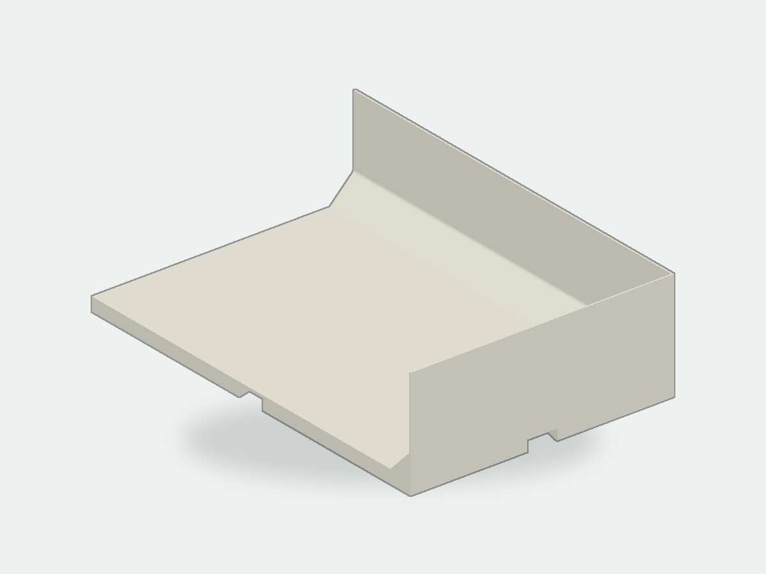
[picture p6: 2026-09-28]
docs/images/h2d-wall-200x300-corner.png

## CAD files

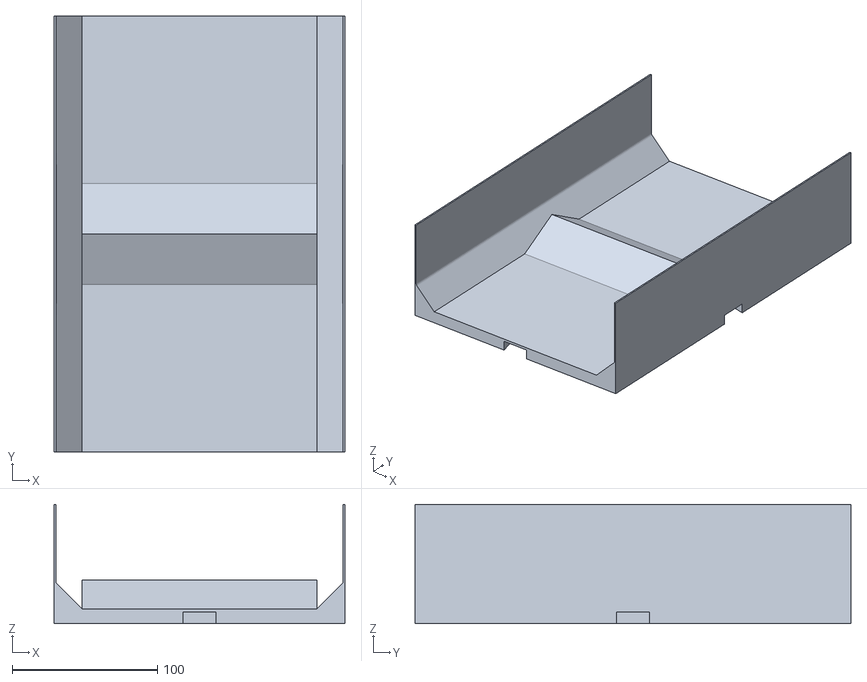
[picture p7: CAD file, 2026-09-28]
output/challenge-ramp-variants/maze_piece_h2d_200x300_low_hill_20mm_rise_v1.stl
200.0 x 300.0 x 82.0

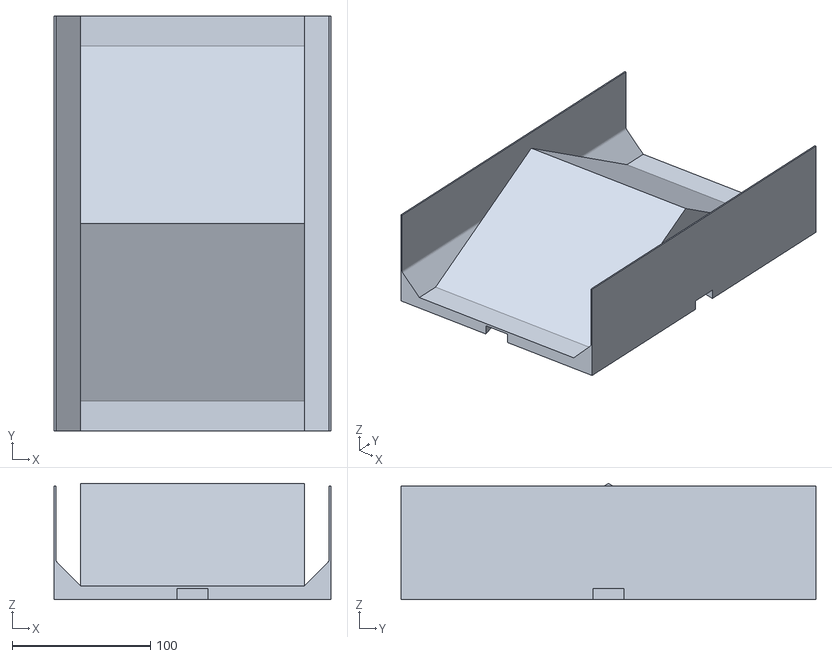
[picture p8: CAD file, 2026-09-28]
output/challenge-ramp/maze_piece_h2d_200x300_30deg_up_down_ramp_v1.stl
200.0 x 300.0 x 84.0

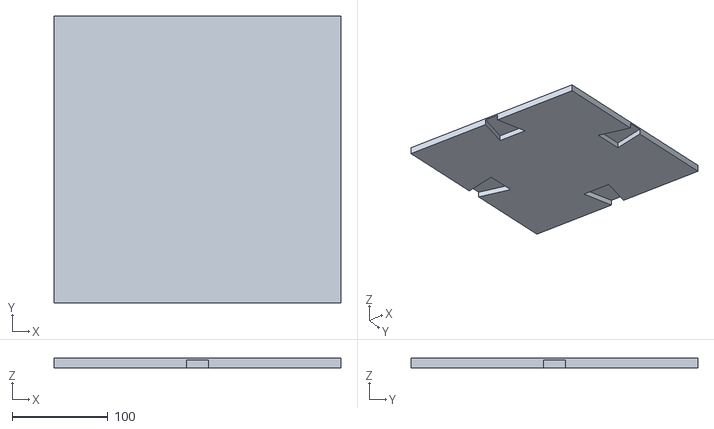
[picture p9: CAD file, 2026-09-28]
output/h2d-platforms/maze_platform_h2d_300x300_v1.stl
300.0 x 300.0 x 10.0

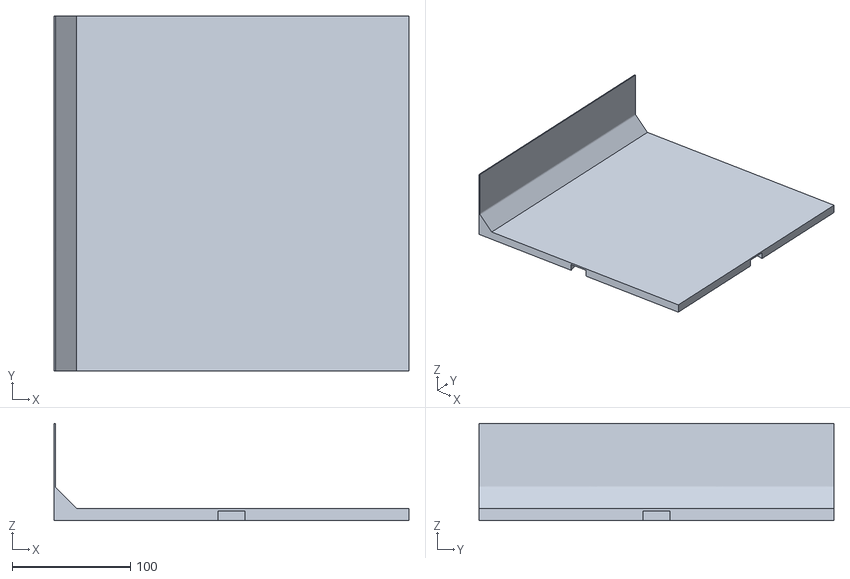
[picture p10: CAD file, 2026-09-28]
output/h2d-wall-variants/maze_piece_h2d_300x300_t_junction_v1.stl
300.0 x 300.0 x 82.0

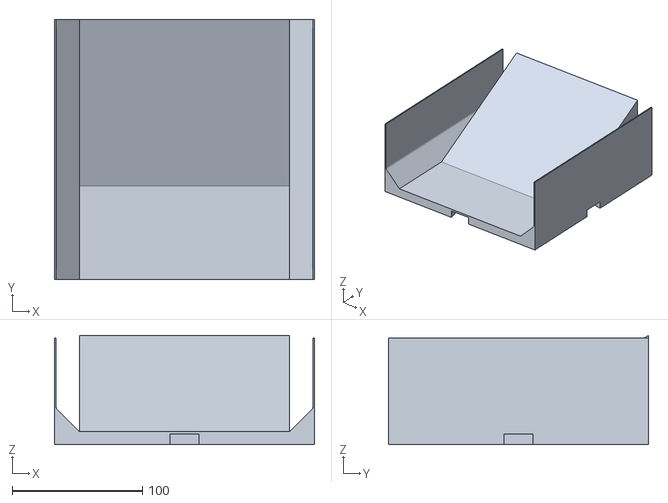
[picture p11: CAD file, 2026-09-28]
output/ramp/maze_piece_x1c_200x200_30deg_ramp_v1.stl
200.0 x 200.0 x 84.0

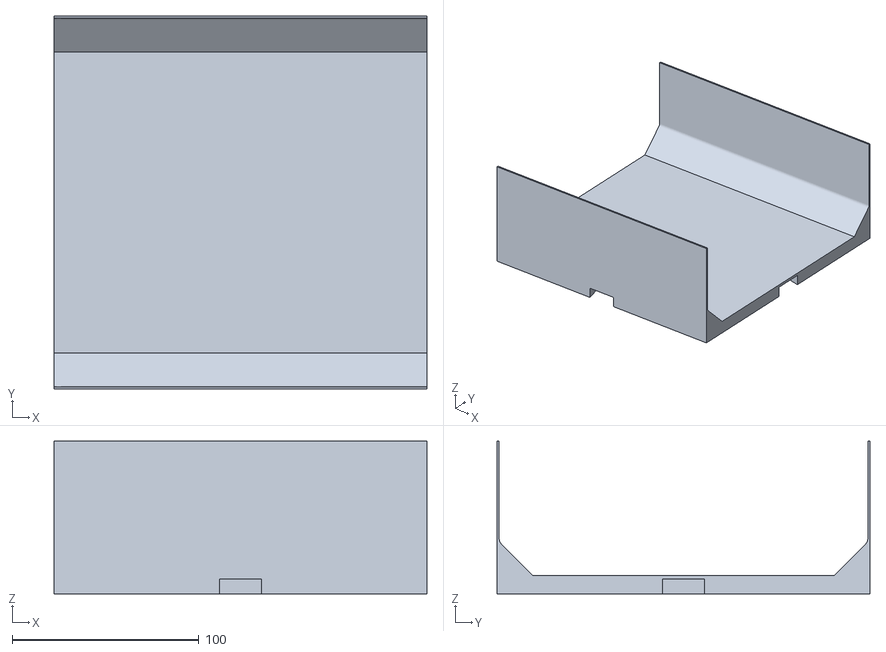
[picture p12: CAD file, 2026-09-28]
output/straight peice.stl
200.0 x 200.0 x 82.0

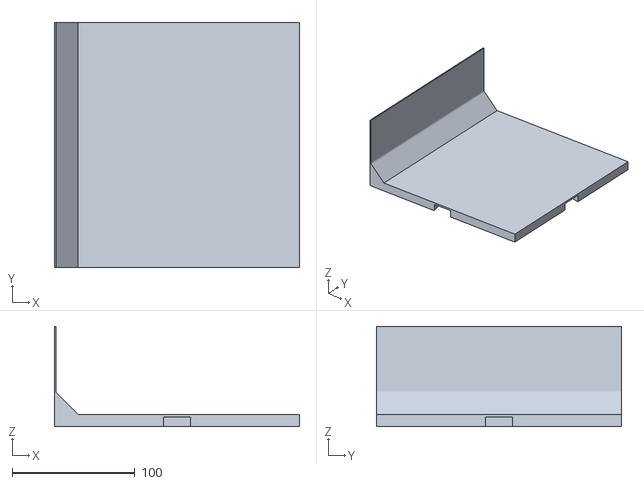
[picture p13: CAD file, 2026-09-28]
output/variants/maze_piece_t_junction_v1.stl
200.0 x 200.0 x 82.0

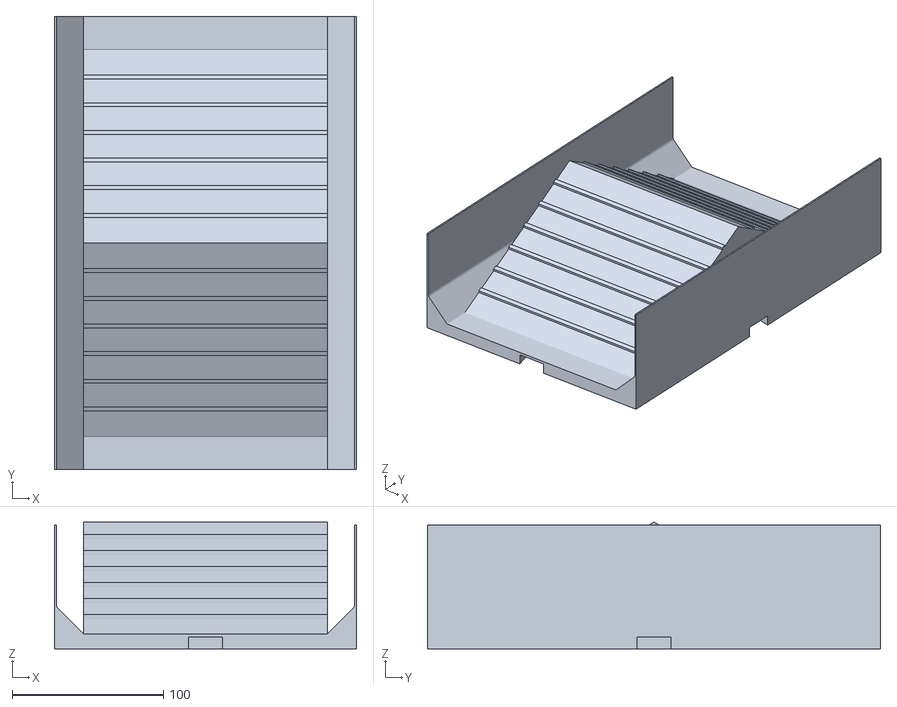
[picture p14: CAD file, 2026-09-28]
output/challenge-ramp-variants/maze_piece_h2d_200x300_traction_ribs_v1.stl
200.0 x 300.0 x 84.0

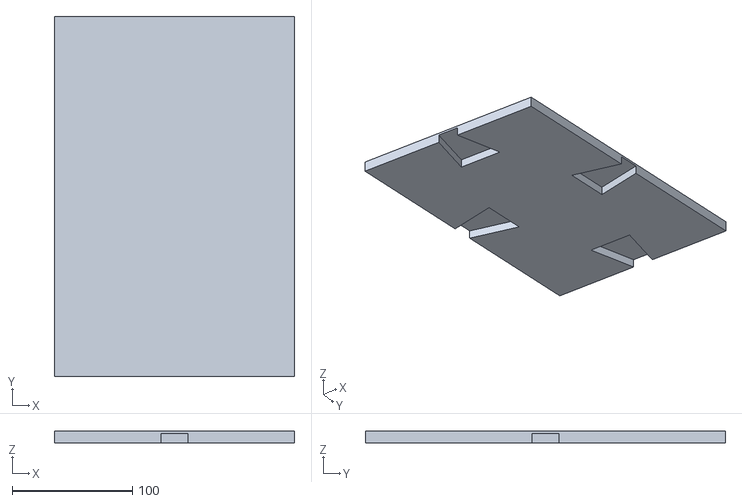
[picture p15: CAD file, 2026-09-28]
output/h2d-platforms/maze_platform_h2d_200x300_v1.stl
200.0 x 300.0 x 10.0

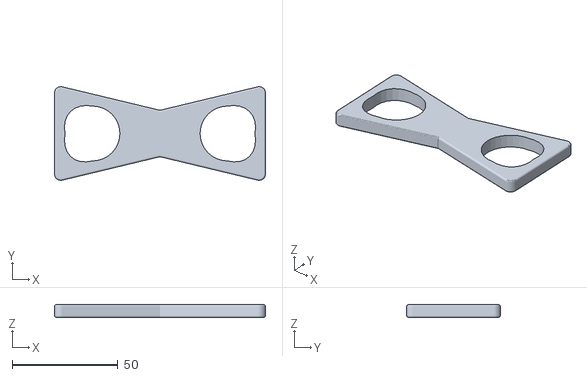
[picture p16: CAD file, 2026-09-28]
output/Maze peice connector.stl
100.0 x 44.4 x 6.00

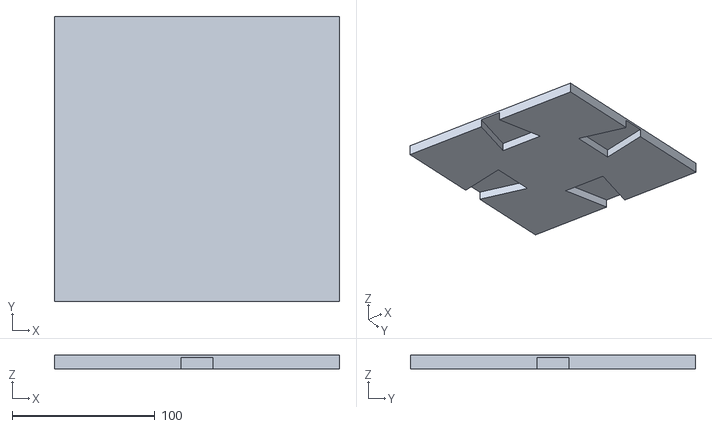
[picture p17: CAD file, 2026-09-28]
output/variants/maze_piece_cross_junction_v1.stl
200.0 x 200.0 x 10.0

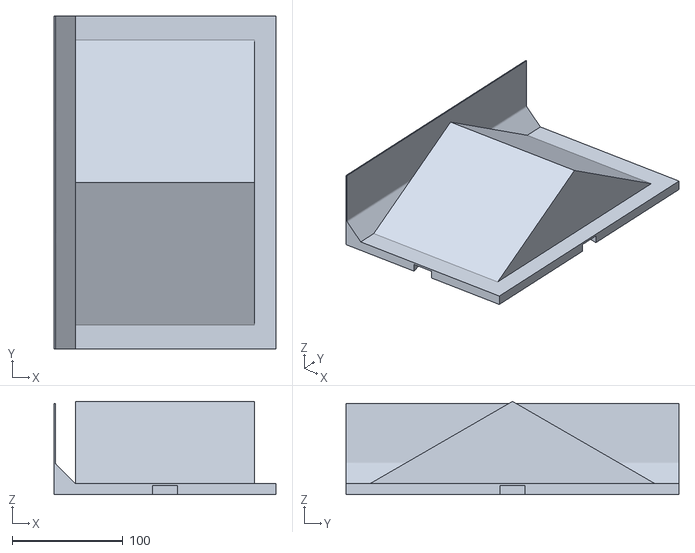
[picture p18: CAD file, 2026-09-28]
output/challenge-ramp-variants/maze_piece_h2d_200x300_single_wall_ridge_v1.stl
200.0 x 300.0 x 84.0

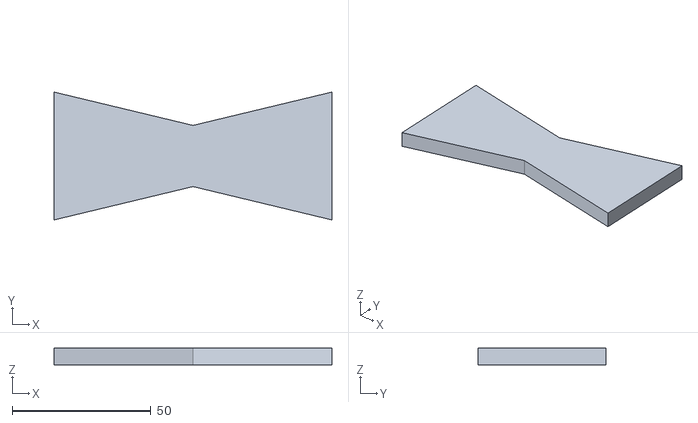
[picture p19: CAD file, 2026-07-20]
output/grid_maze_platform_bridge_v1.stl
100.0 x 46.0 x 6.00

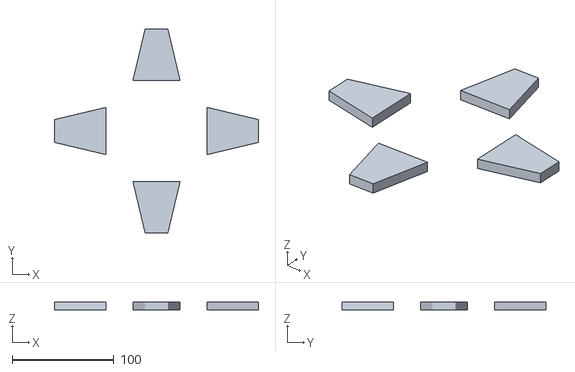
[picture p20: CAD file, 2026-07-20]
output/grid_maze_platform_recess_cutter_v1.stl
200.4 x 200.4 x 8.00

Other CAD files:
output/h2d-wall-variants/maze_piece_h2d_200x300_cross_junction_v1.stl
output/h2d-wall-variants/maze_piece_h2d_200x300_straight_v1.stl
output/variants/maze_piece_corner_v1.stl
output/challenge-ramp-variants/maze_piece_h2d_200x300_offset_ridge_v1.stl
output/challenge-ramp-variants/maze_piece_h2d_200x300_central_platform_80mm_v1.stl
output/challenge-ramp-variants/maze_piece_h2d_200x300_challenge_variants_v1.3dm
output/challenge-ramp-variants/maze_piece_h2d_200x300_double_hump_30mm_rise_v1.stl
output/challenge-ramp-variants/maze_piece_h2d_200x300_flat_top_30mm_v1.stl
output/challenge-ramp-variants/maze_piece_h2d_200x300_low_hill_40mm_rise_v1.stl
output/challenge-ramp-variants/maze_piece_h2d_200x300_low_hill_60mm_rise_v1.stl
output/challenge-ramp-variants/maze_piece_h2d_200x300_open_sides_ridge_v1.stl
output/challenge-ramp-variants/maze_piece_h2d_200x300_ramp_up_steps_down_v1.stl
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

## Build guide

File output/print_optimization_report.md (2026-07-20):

# Grid Maze Platform 3D Print Optimization

Profile: `balanced`

## Baseline

- tile 200 x 200 x 10.0 mm, pocket 8.0 mm, skin 2.0 mm, dovetail 50 x 22/46 mm, connector 6.0 mm, clearance 0.20 mm, sides north,south,east,west
- Baseline score: 10.00
- clearance 0.20 mm, dovetail 50 x 22/46 mm, connector 6.0 mm, slack 2.0 mm, angle 13.5 deg
- Warning: 0.20 mm clearance is a tuned-printer fit; print a connector coupon first

## Printability Checks

- `pass` platform stack is 10 mm total, 8 mm underside recess, 2 mm top skin
- `review` pocket clearance is 0.20 mm per side
- `pass` connector sits 2.0 mm below the pocket roof
- `pass` dovetail taper angle is 13.5 degrees per side
- `info` 4 selected side pocket(s): north, south, east, west
- `info` estimated bridge volume is 20.4 cm3
- `info` estimated selected pocket removal is 55.3 cm3

## Recommended Variant

- Score: 0.00
- tile 200 x 200 x 10.0 mm, pocket 8.0 mm, skin 2.0 mm, dovetail 50 x 22/42 mm, connector 6.0 mm, clearance 0.25 mm, sides north,south,east,west
- clearance 0.25 mm, dovetail 50 x 22/42 mm, connector 6.0 mm, slack 2.0 mm, angle 11.3 deg

## Top Candidates

1. score 0.00: clearance 0.25 mm, dovetail 50 x 22/42 mm, connector 6.0 mm, slack 2.0 mm, angle 11.3 deg
2. score 0.00: clearance 0.25 mm, dovetail 50 x 22/44 mm, connector 6.0 mm, slack 2.0 mm, angle 12.4 deg
3. score 0.00: clearance 0.25 mm, dovetail 50 x 22/46 mm, connector 6.0 mm, slack 2.0 mm, angle 13.5 deg
4. score 0.00: clearance 0.25 mm, dovetail 50 x 22/48 mm, connector 6.0 mm, slack 2.0 mm, angle 14.6 deg
5. score 0.00: clearance 0.25 mm, dovetail 50 x 22/50 mm, connector 6.0 mm, slack 2.0 mm, angle 15.6 deg
6. score 0.16: clearance 0.25 mm, dovetail 50 x 20/42 mm, connector 6.0 mm, slack 2.0 mm, angle 12.4 deg
7. score 0.16: clearance 0.25 mm, dovetail 50 x 24/42 mm, connector 6.0 mm, slack 2.0 mm, angle 10.2 deg
8. score 0.16: clearance 0.25 mm, dovetail 50 x 20/44 mm, connector 6.0 mm, slack 2.0 mm, angle 13.5 deg

## Practical Notes

- Keep printing the connector flat on the bed; this design has no intentional overhang lock.
- Print one bridge plus a short edge-pocket coupon before committing to full tiles.
- Use the `tight` profile if your printer reliably handles 0.20 mm clearance.
- Use the `balanced` profile for a more forgiving first FDM prototype.
- The optimizer does not overwrite `params/maze_platform_v1.json`; use `--write-params` to create a separate optimized JSON.

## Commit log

2026-07-20 Publish parametric grid maze platform
    [grid_maze_platform_10mm_v1.3dm, grid_maze_platform_bridge_v1.stl, grid_maze_platform_recess_cutter_v1.stl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]
2026-08-30 Add standalone Maskwa Maze Lab game and deployment
    [maze_piece_corner_v1.stl, maze_piece_end_v1.stl, maze_piece_straight_v1.stl]
2026-09-28 Add printable maze variants and offline visual catalog
    [Maze peice connector.stl, maze_piece_corner_v1.stl, maze_piece_cross_junction_v1.stl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]
